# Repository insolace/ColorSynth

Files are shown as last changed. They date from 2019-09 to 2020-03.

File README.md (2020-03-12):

# ColorSynth<br>
MIDI Controlled Light Synthesizer<br>
Created by Eric Bateman

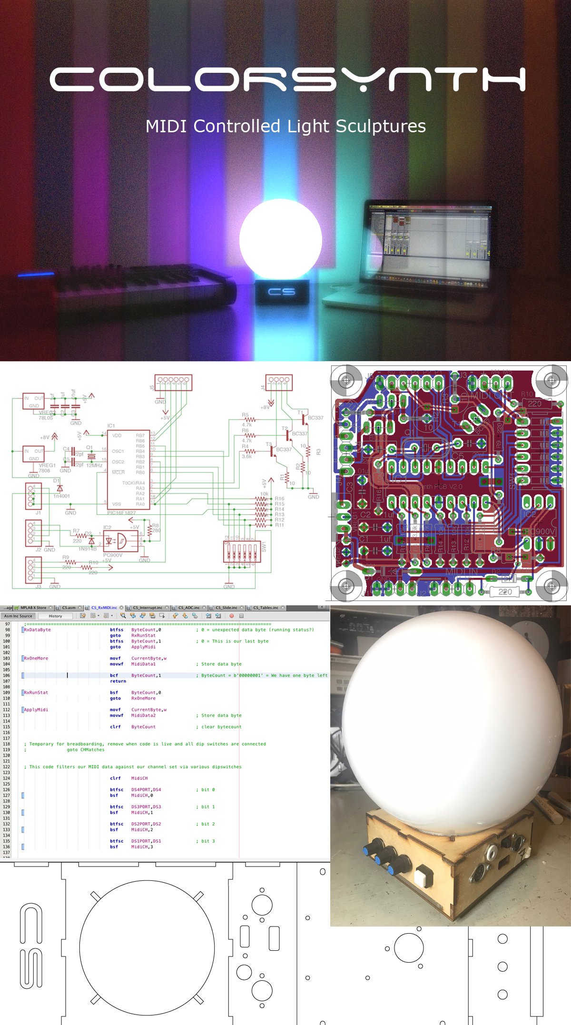
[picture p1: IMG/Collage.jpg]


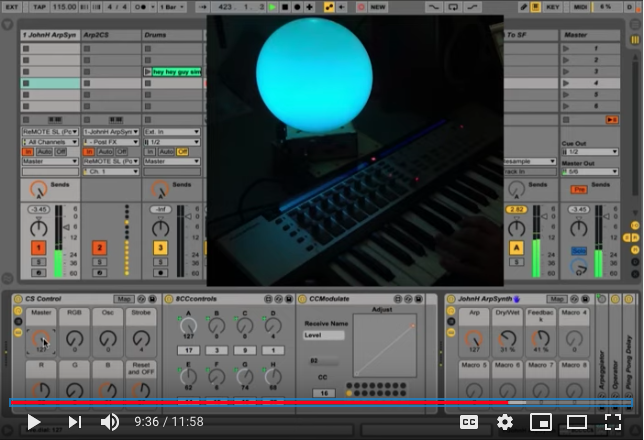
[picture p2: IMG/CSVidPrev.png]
DEMO VIDEO (https://www.youtube.com/watch?v=AM1KORBaHBU)


ColorSynth is a MIDI controlled sculpture and light synthesizer.  
* Lightning fast strobe and oscillators, written in PIC assembly
* Super bright 3W RGB LEDs
* Power over MIDI, daisy chainable
* Responds to note on and control change events, instant lighting for your MIDI equipped instrument

Visit http://www.colorsynth.com

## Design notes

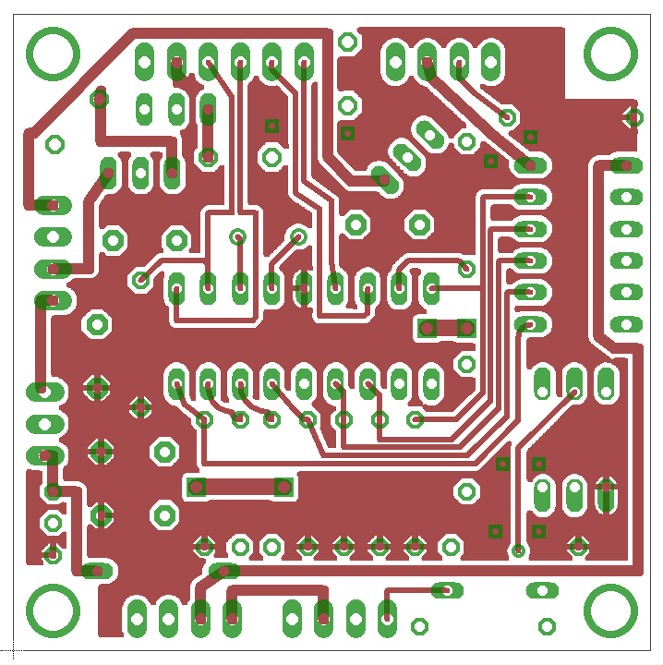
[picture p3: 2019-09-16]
PCB and Schematic/PCB Render/CS-PCB-V2.0-top.jpg

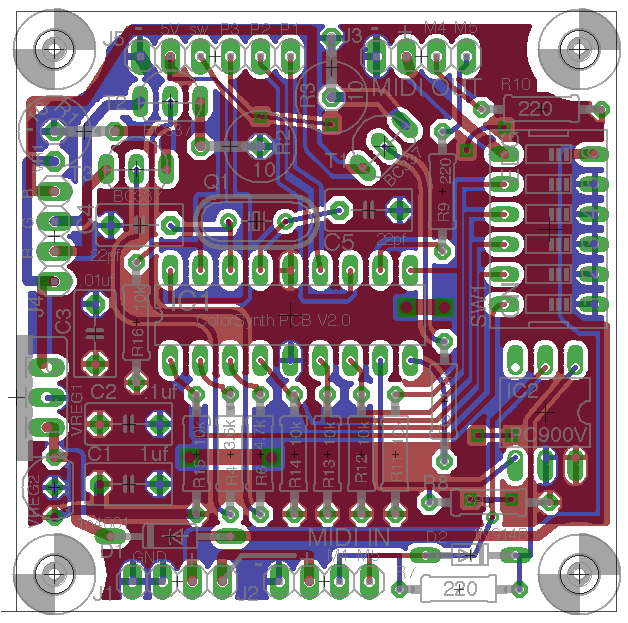
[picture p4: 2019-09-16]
PCB and Schematic/ColorSynth 2.0 PCB.png

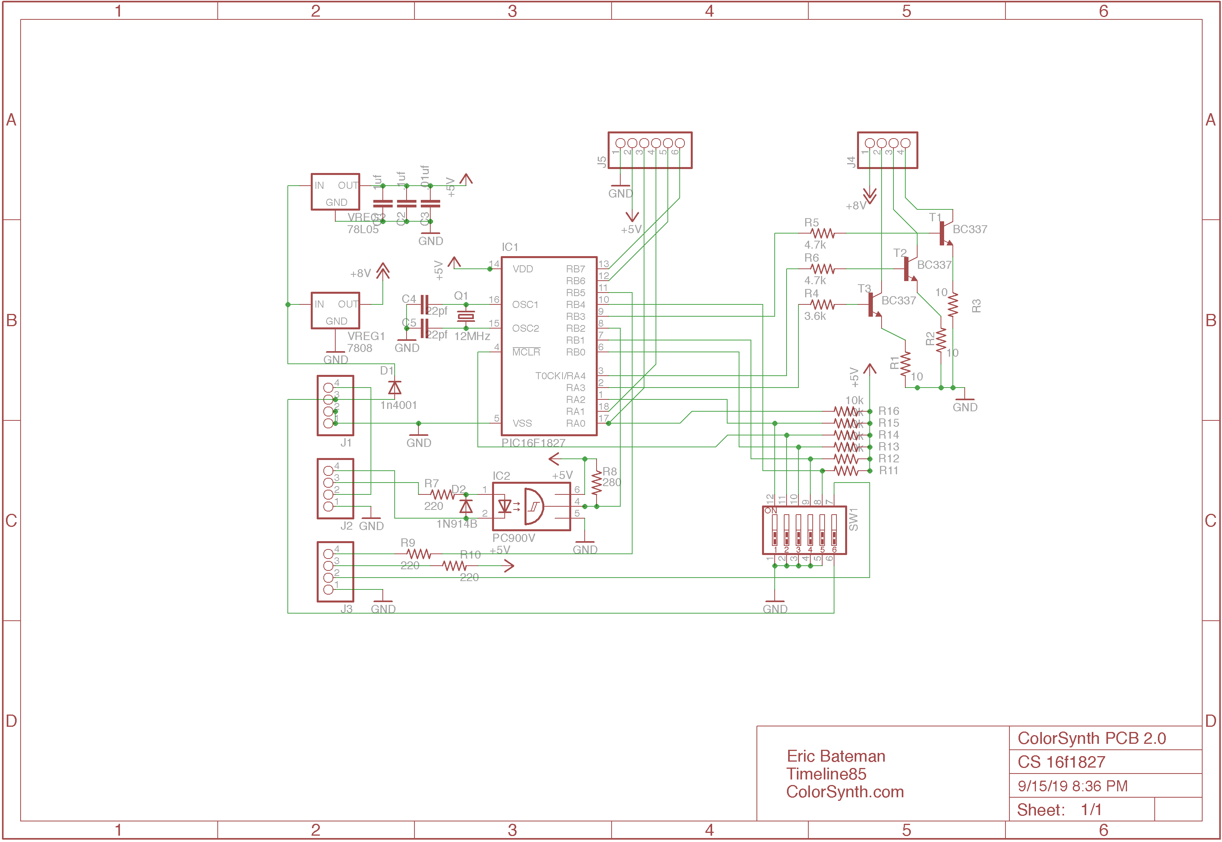
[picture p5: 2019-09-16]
PCB and Schematic/ColorSynth 2.0 Schematic.png

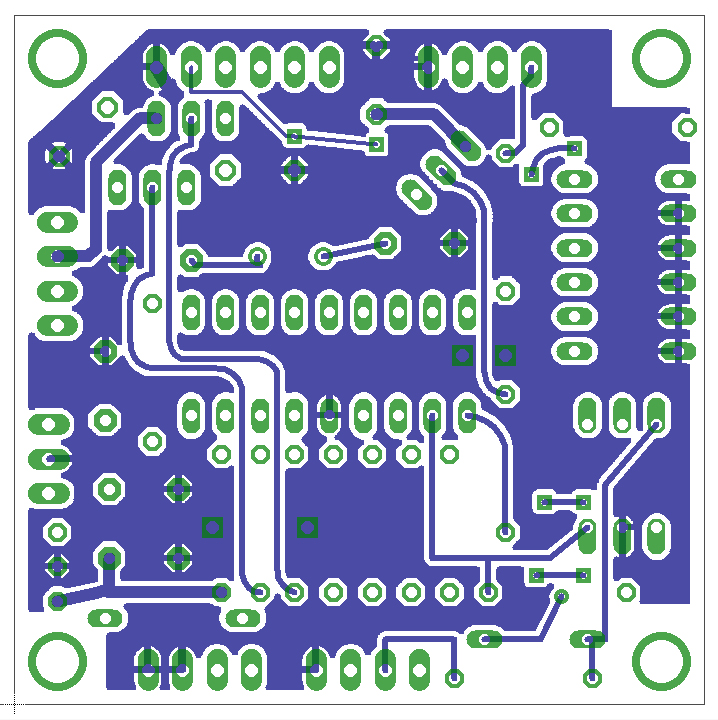
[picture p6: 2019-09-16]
PCB and Schematic/PCB Render/CS-PCB-V2.0-bottom.jpg

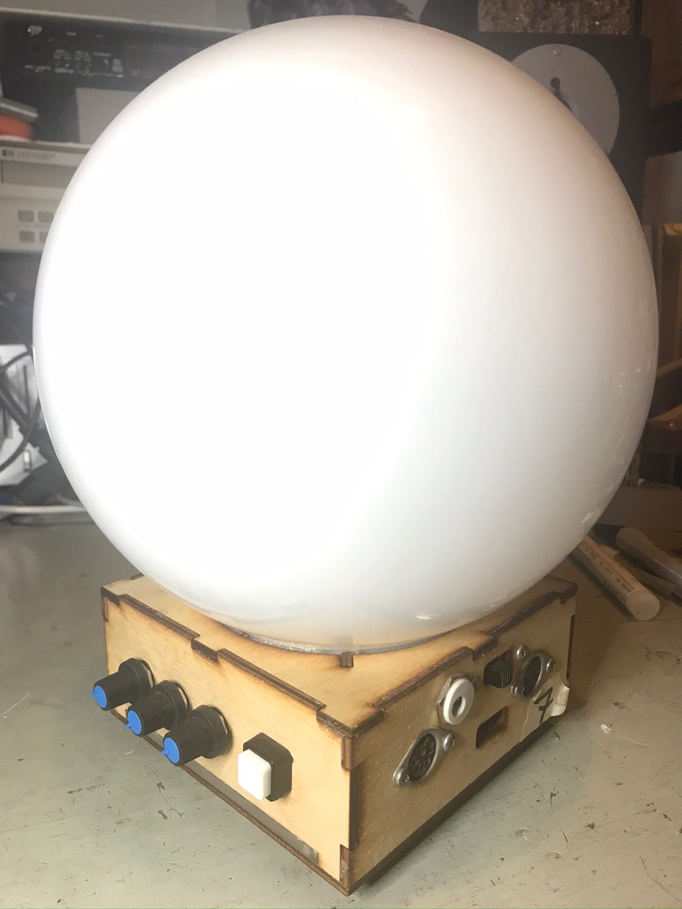
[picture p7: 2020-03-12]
IMG/CS3.jpg

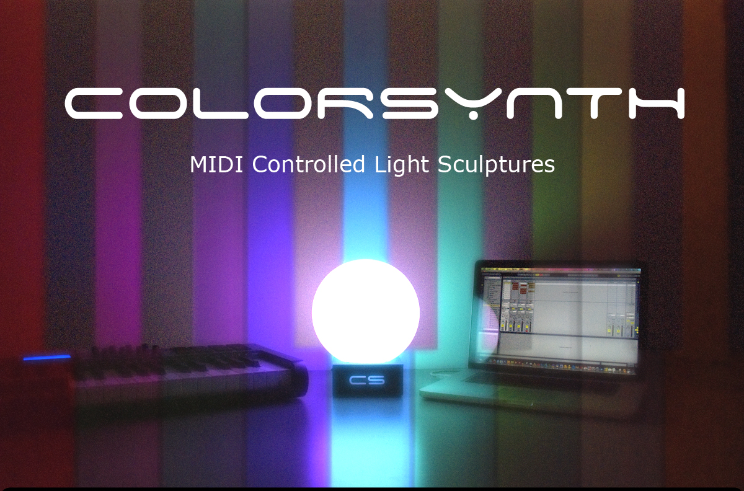
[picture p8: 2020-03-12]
IMG/Background-w-text.jpg

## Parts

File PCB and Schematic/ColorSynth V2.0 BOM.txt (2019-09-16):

ColorSynth PCB/Schematic v2.0 Bill of Materials
Written 2010-01-03 by Eric Bateman
eric@colorsynth.com

Most parts should be easily found at Mouser.com

(1) FIXTURE - available as a kit from ColorSynth.com

(1) Common Anode RGB 3W LED, 350mA max per color.  Voltages can be 1v to 5v for any color, the circuit will compensate
(1) 12V DC power supply, unregulated, 500mA current per ColorSynth
(2) 5 PIN DIN style connectors for MIDI I/O
(1) DC power jack
(1) Power switch (optional).  A selector switch can be used to toggle between external or MIDI power.

(1) Microchip PIC16F1827I/P - IC1
(1) Sharp PC900V optocoupler - IC2
(1) LM7808 DC regulator - VREG1
(1) 78L05 DC regulator - VREG2
(1) 12MHz crystal - Q1
(1) 6 position dip switch, right angle - SW1

(1) 1uf ceramic capacitor - C1
(1) .1uf ceramic capacitor - C2
(1) .01uf ceramic capacitor - C3
(2) 22pf ceramic capacitor - C4, C5

(1) 1N4001 protectio diode - D1
(1) 1N914B diode - D2

(3) 10ohm 1W thru hole resistors - R1, R2, R3
(1) 3.6k ohm 1/4w thru hole resistor - R4
(2) 4.7k ohm 1/4w thru hole resistors - R5, R6
(3) 220 ohm 1/4w thru hole resistors - R7, R9, R10
(1) 280 ohm 1/4w thru hole resistor - R8
(6) 10k ohm 1/4w or 1/8w thru hole resistors - R11, R12, R13, R14, R15, R16

(3) BC337 NPN transistors - T1, T2, T3

(5) .100" spaced pin headers, 4pins each except for J5 which needs 6 pins.

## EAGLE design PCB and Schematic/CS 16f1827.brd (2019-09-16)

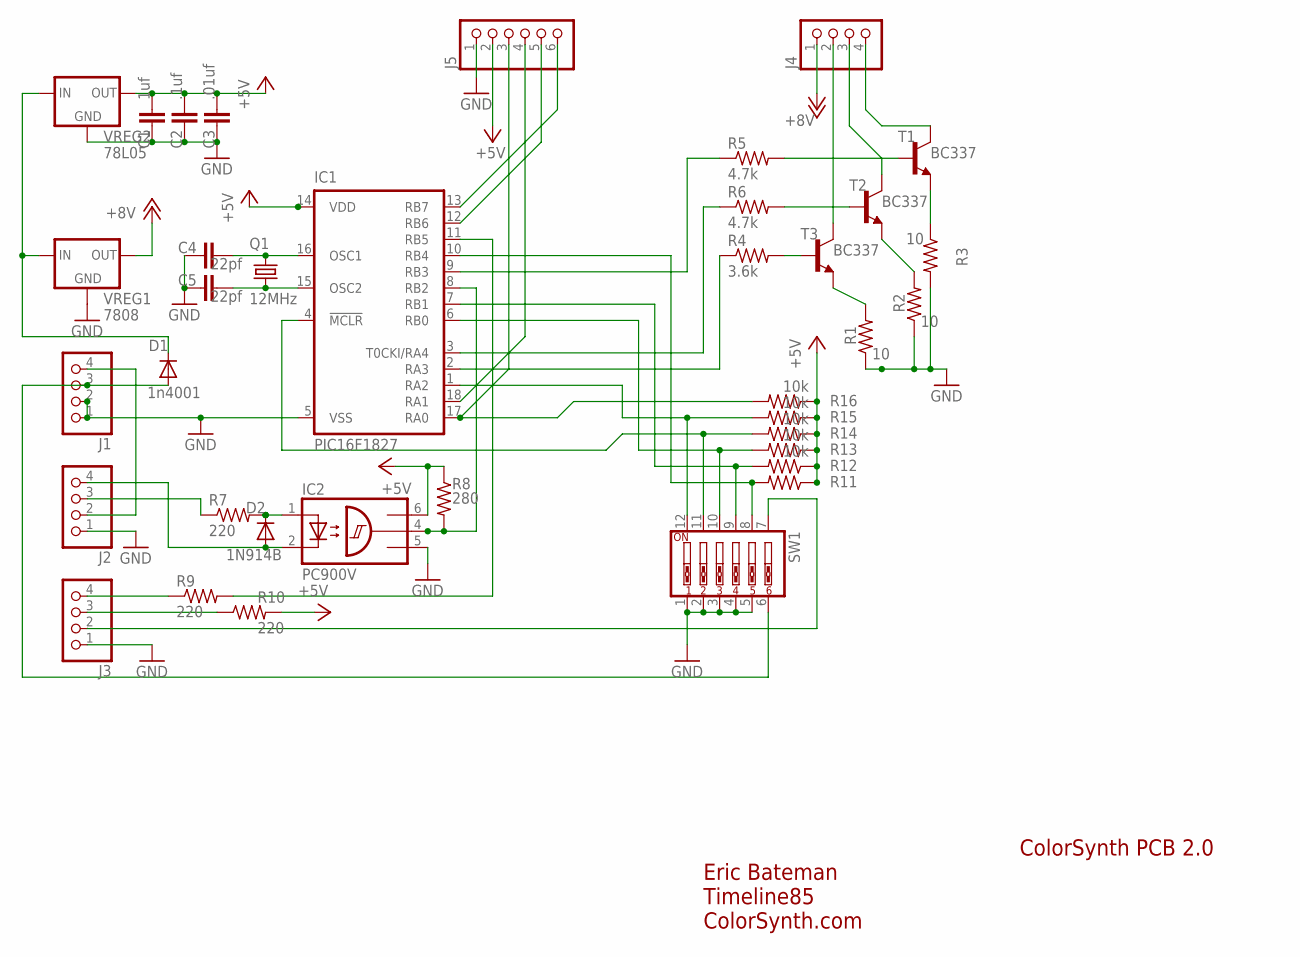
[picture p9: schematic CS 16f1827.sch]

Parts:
C1: 1uf; C5B3.5
C2: .1uf; C5B3.5
C3: .01uf; C5B3.5
C4, C5: 22pf; C5B3.5
D1: 1n4001; DO35-10
D2: 1N914B; DO34-7
IC1: PIC16F1827; DIL18
IC2: PC900V; DIL06
J1, J2, J3, J4: PINHD-1X4; 1X04
J5: PINHD-1X6; 1X06
Q1: 12MHz; HC49/S
R1, R2, R3: 10; 0617V
R4: 3.6k; 0207/10
R5, R6: 4.7k; 0207/10
R7, R9, R10: 220; 0207/10
R8: 280; 0207/10
R11, R12, R13, R14, R15, R16: 10k; 0207/10
SW1: SW_DIP-6; EDG-06
T1, T2, T3: BC337; TO92-CBE
VREG1: 7808; 78XXS
VREG2: 78L05; 78LXX

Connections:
5V: C1.1, C2.1, C3.1, IC1.14 (VDD), IC2.6 (VCC), J5.2, R8.1, R10.2, R11.1, R12.1, R13.1, R14.1, R15.1, R16.1, VREG2.OUT
GND: C1.2, C2.2, C3.2, C4.2, C5.2, IC1.5 (VSS), IC2.5 (GND), J1.1, J1.2, J2.1, J3.1, J5.1, R1.1, R2.1, R3.2, SW1.1, SW1.2, SW1.3, SW1.4, SW1.5, VREG1.GND, VREG2.GND
unnamed: D2.A, IC2.2 (C), J2.4
unnamed: D2.C, IC2.1 (A), R7.2
unnamed: R5.2, T1.B
unnamed: IC1.10 (RB4), R11.2, SW1.8
unnamed: R1.2, T3.E
unnamed: C4.1, IC1.16 (OSC1), Q1.1
unnamed: C5.1, IC1.15 (OSC2), Q1.2
unnamed: IC1.2 (RA3), R4.1
unnamed: IC1.12 (RB6), J5.5
unnamed: IC1.3 (T0CKI/RA4), R6.1
unnamed: IC1.9 (RB3), R5.1
unnamed: R6.2, T2.B
unnamed: R4.2, T3.B
unnamed: J4.2, T3.C
unnamed: IC1.7 (RB1), R12.2, SW1.9
unnamed: R2.2, T2.E
unnamed: IC1.6 (RB0), R13.2, SW1.10
unnamed: IC1.4 (!MCLR), R14.2, SW1.11
unnamed: IC1.1 (RA2), R15.2, SW1.12
unnamed: IC1.18 (RA1), J5.4
unnamed: IC1.17 (RA0), J5.3, R16.2
unnamed: R3.1, T1.E
unnamed: IC1.8 (RB2), IC2.4 (OUT), R8.2
unnamed: D1.A, J1.3, SW1.6
unnamed: J4.1, VREG1.OUT
unnamed: IC1.11 (RB5), R9.2
unnamed: IC1.13 (RB7), J5.6
unnamed: J3.4, R9.1
unnamed: J3.3, R10.1
unnamed: J2.3, R7.1
unnamed: J1.4, J2.2
unnamed: J3.2, SW1.7
unnamed: J4.3, T2.C
unnamed: D1.C, VREG1.IN, VREG2.IN
unnamed: J4.4, T1.C

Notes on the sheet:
Eric Bateman Timeline85 ColorSynth.com
ColorSynth PCB 2.0

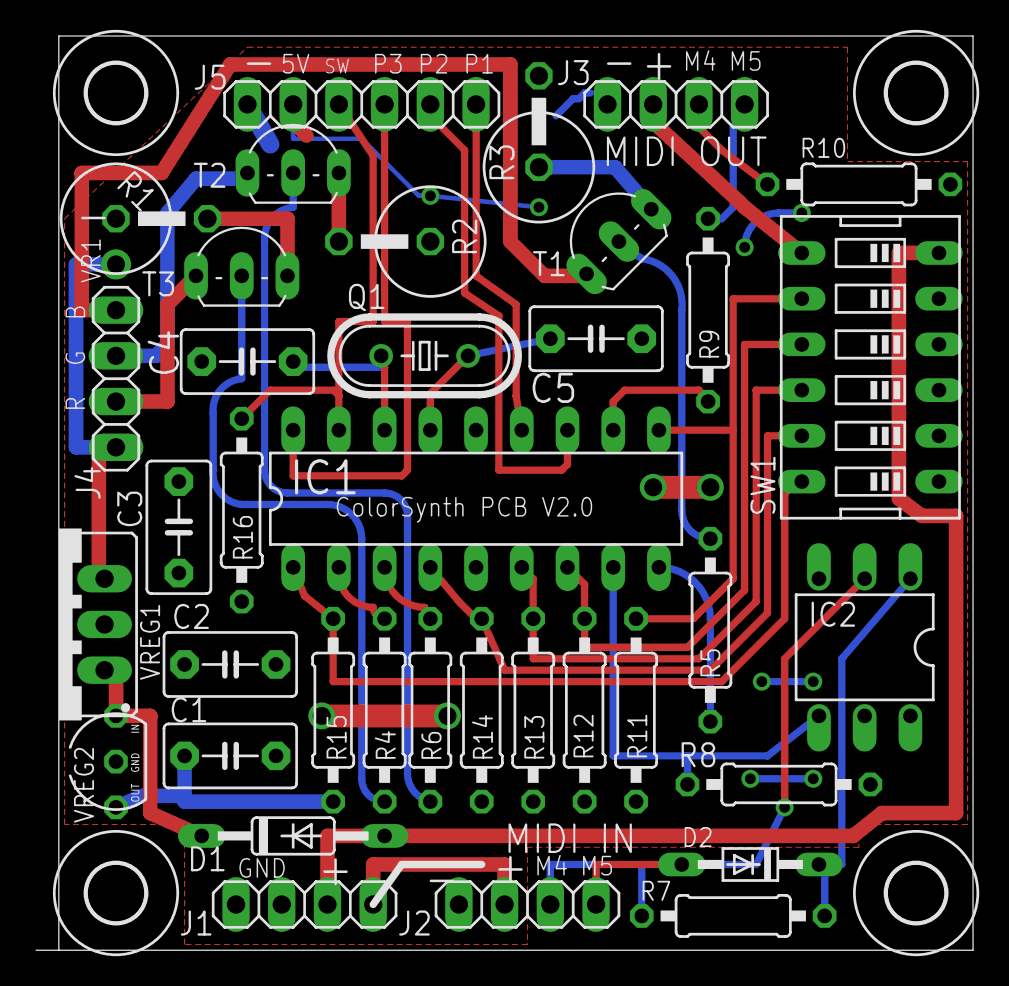
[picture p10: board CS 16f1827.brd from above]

Board: 2 copper layers, 52.1 x 50.8 mm, 41 parts (0 on the bottom side), 37 nets.

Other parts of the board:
U$1, U$2, U$3, U$4: 3,2
